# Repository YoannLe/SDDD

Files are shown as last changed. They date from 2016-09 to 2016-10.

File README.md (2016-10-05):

# SDDD

This is a simple direct drive desulfaltor for lead acid battery 12V blocs

You can find schematic, PCB and Gerber files to build a direct drive desulfaltor circuit. This circuit pulses a high current from 30 to 100A at about 2kHz into the battery block to break lead sulfate cristals.

The pulse board drives MOSFET with impulsions from 555 and discharges the capacitor bank into the battery bloc. The capacitor bank is load at 30V DC through a 10W resistor to limit charge current, different values of resistors can be selected to adapt the power of desulfator to the sulfated battery.
Capacitor bank is made with very low ESR electrolytic caps in parallel, the capacity is about 30 mf, in my case:  30 x 1000µf 63V ESR=43mΩ PANASONIC EEUFC1J102U

# SDDD Pulse Board

The main board is the pulse generator board, it drives Mosfets:

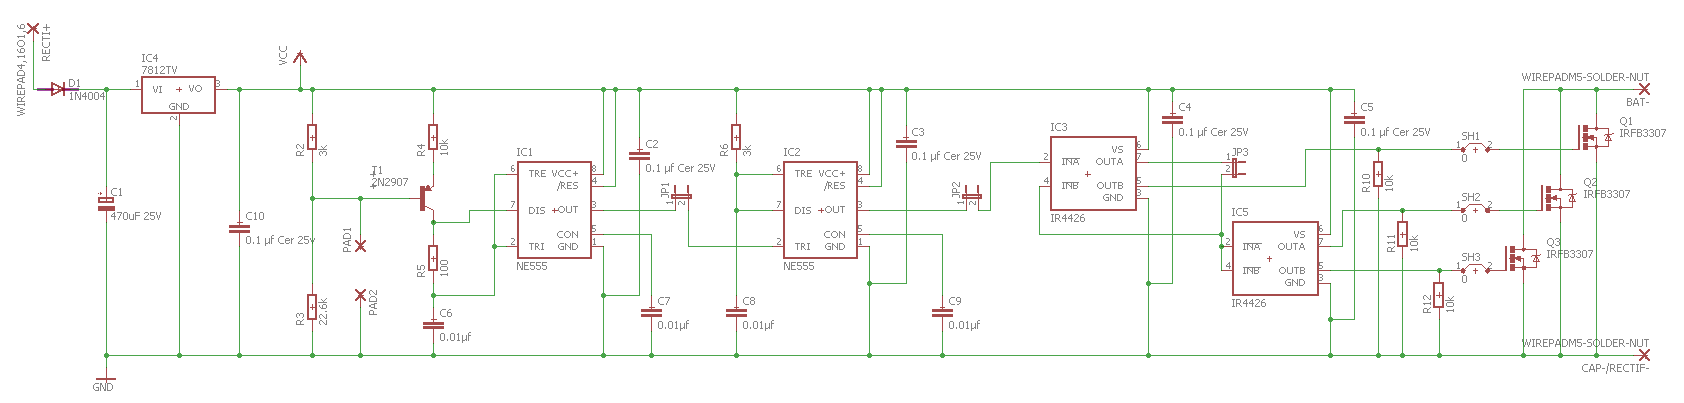
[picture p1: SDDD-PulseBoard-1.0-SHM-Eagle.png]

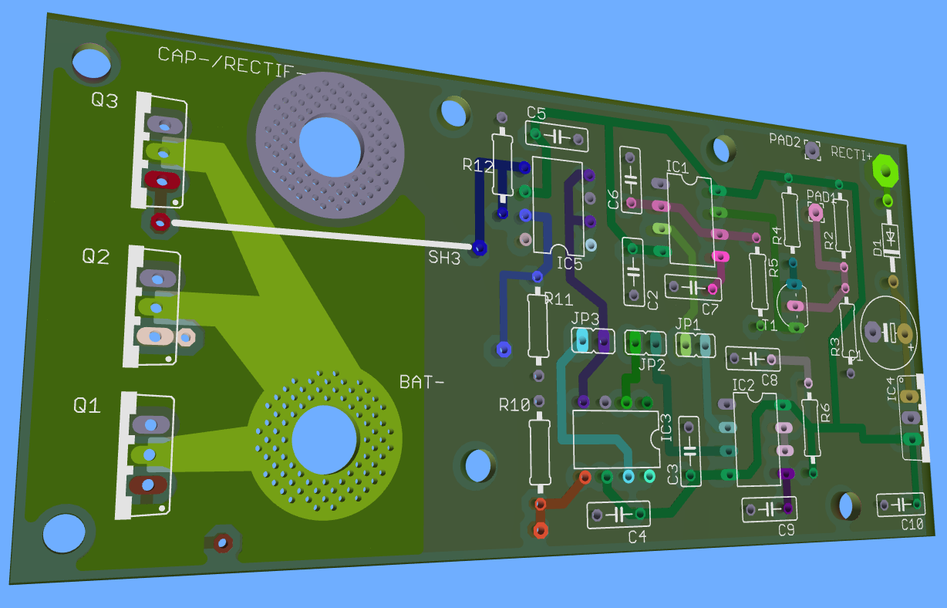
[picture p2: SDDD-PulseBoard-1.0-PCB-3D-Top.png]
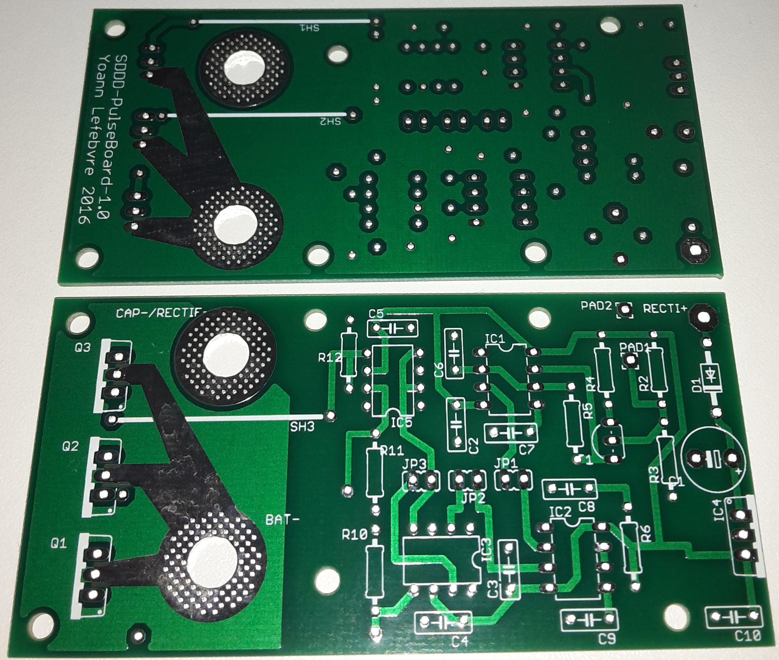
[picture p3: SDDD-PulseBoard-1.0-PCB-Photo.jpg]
 

Frequency and pulses timming can be calculated as described by Tucsonshooter:

>Pulse width = 1.1 * R6 * C8         (capacitance in farads,  .01 mF = .00000001 farads). 
>Example: 1.1 * 3000*.00000001 = .000033 seconds or 33 microseconds.
>
>Frequency = (R2 * Vcc - .65(R2+R3)) / (.333 * Vcc * R4(R2+R3) * C6)
>In this case Vcc = 12V
>And remember capacitance is in farads. Watch the parentheses (X +Y) 
>
>Example: (3000 * 12 - .65( 3000 + 22500))/ (.333 * 12 * 10000(3000 + 22500) * .00000001 =    (36000-16575) / 10.1898     = 1906 Hertz
>
>The frequency formula looks complicated but it is just adding and multiplying in the right order. If you break the formula down and put >it in Excell it will be much easier.
>
>Thermistors 
>  Remember - a 3K NTC thermistor will read 3K at room temperature (25 deg. C.). It will read about 1.5K at 45 deg.C.

A 3k NTC could be used for R2 to reduce frequency from 2kHz at 24° to 250Hz at 45°, this reduce the average power in the MOSFET and protects it from overheat on good batteries with low internal resistances. This slows frequency when the sulfated battery recovers its capacity and low internal resistance.

This board can be cut in fonction blocs when opening jumpers, this is usefull for testing and try others configurations. An optocoupler connected to Vcc and PAD1 can be use to stop pulses from an MCU or arduino. Stop pulsing can be usefull to control battery voltage or in case of battery overheating. 

# Capacitor bank and power supply

# Assembly

# Tests

# Results on 12V 90Ah AGM Battery

First if the battery is old and have been over charged, open the sealed battery to check electrolyte level and refill with demineralized water. The level must be just above the glass mast.

#References

Forum Direct Drive Desulfator Design:

http://leadacidbatterydesulfation.yuku.com/topic/1162/Direct%E2%88%92Drive%E2%88%92Desulfator%E2%88%92Design
http://leadacidbatterydesulfation.yuku.com/topic/1246/Simple-Direct-Drive-Desulfator-PCB-thread
http://www.courtiestown.co.uk/fileuploader/download/download/?d=0&file=custom%2Fupload%2FFile-1368475803.pdf

Evolutions:

http://www.brettcave.net/howto/circuits/Battery_LeadAcidDesulfator-DirectDrive-Type2.pdf
http://www.brettcave.net/howto/circuits/Battery_LeadAcidDesulfator-DirectDrive-Type3.pdf

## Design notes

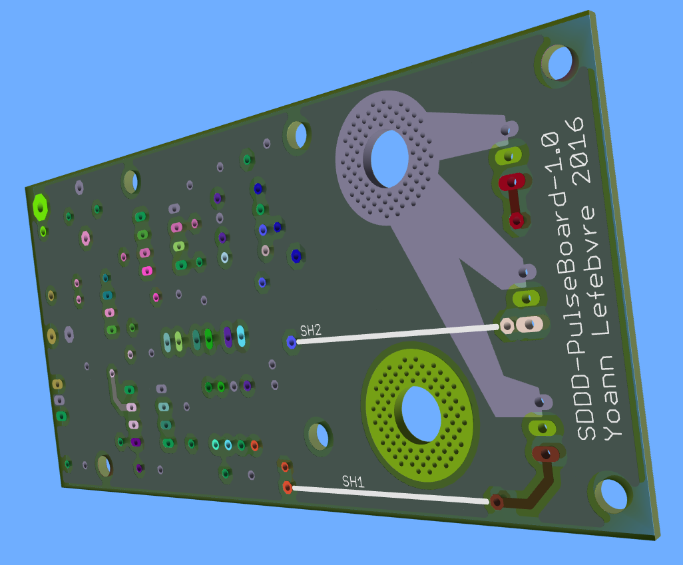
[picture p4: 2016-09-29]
SDDD-PulseBoard-1.0-PCB-3D-Back.png

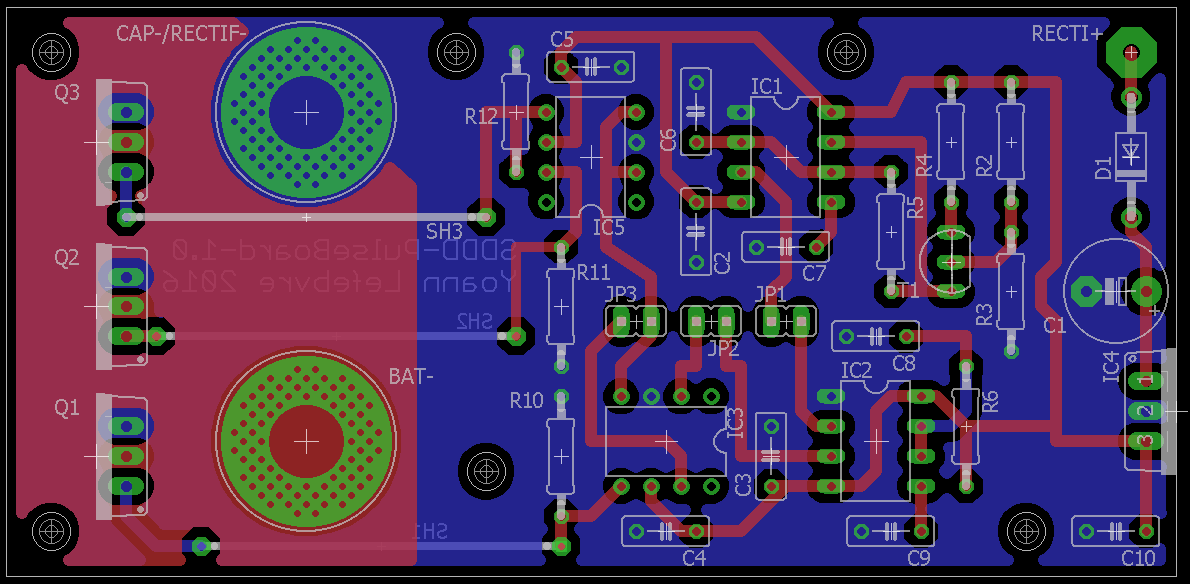
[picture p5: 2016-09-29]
SDDD-PulseBoard-1.0-PCB-Eagle.png

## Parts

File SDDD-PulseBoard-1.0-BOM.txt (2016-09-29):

Partlist exported from D:/ylefebvre/Bureau/SDDD/SDDD-Eagle/SDDD-PulseBoard-1.0.sch at 29/09/2016 18:44

Part         Value                Device                Package       Description                          MF                          MPN       OC_FARNELL OC_NEWARK
BAT-         WIREPADM5-SOLDER-NUT WIREPADM5-SOLDER-NUT  M5-SOLDER-NUT Wire PAD connect wire on PCB                                                                   
C1           470uF 25V            CPOL-EUE5-8.5         E5-8,5        POLARIZED CAPACITOR, European symbol                                                           
C2           0.1 µf Cer 25V       C-EU050-025X075       C050-025X075  CAPACITOR, European symbol                                                                     
C3           0.1 µf Cer 25V       C-EU050-025X075       C050-025X075  CAPACITOR, European symbol                                                                     
C4           0.1 µf Cer 25V       C-EU050-025X075       C050-025X075  CAPACITOR, European symbol                                                                     
C5           0.1 µf Cer 25V       C-EU050-025X075       C050-025X075  CAPACITOR, European symbol                                                                     
C6           0.01µf               C-EU050-025X075       C050-025X075  CAPACITOR, European symbol                                                                     
C7           0.01µf               C-EU050-025X075       C050-025X075  CAPACITOR, European symbol                                                                     
C8           0.01µf               C-EU050-025X075       C050-025X075  CAPACITOR, European symbol                                                                     
C9           0.01µf               C-EU050-025X075       C050-025X075  CAPACITOR, European symbol                                                                     
C10          0.1 µf Cer 25v       C-EU050-025X075       C050-025X075  CAPACITOR, European symbol                                                                     
CAP-/RECTIF- WIREPADM5-SOLDER-NUT WIREPADM5-SOLDER-NUT  M5-SOLDER-NUT Wire PAD connect wire on PCB                                                                   
D1           1N4004               1N4004                DO41-10       DIODE                                                                                          
IC1          NE555                NE555                 DIL-08        General purpose bipolar Timer        Arrow Electronics           NE555N    1467742    89K1486  
IC2          NE555                NE555                 DIL-08        General purpose bipolar Timer        Arrow Electronics           NE555N    1467742    89K1486  
IC3          IR4426               IR4426                DIL08         DUAL LOW SIDE DRIVER                 INTERNATIONAL RECTIFIER(IR) IR4426PBF 1023265    19K8460  
IC4          7812TV               7812TV                TO220V        Positive VOLTAGE REGULATOR                                                                     
IC5          IR4426               IR4426                DIL08         DUAL LOW SIDE DRIVER                 INTERNATIONAL RECTIFIER(IR) IR4426PBF 1023265    19K8460  
JP1                               JP1E                  JP1           JUMPER                                                                                         
JP2                               JP1E                  JP1           JUMPER                                                                                         
JP3                               JP1E                  JP1           JUMPER                                                                                         
PAD1                              2,15/1,0              2,15/1,0      THROUGH-HOLE PAD                                                                               
PAD2                              2,15/1,0              2,15/1,0      THROUGH-HOLE PAD                                                                               
Q1           IRFB3307             IRF540                TO220BV       HEXFET Power MOSFET                                                                            
Q2           IRFB3307             IRF540                TO220BV       HEXFET Power MOSFET                                                                            
Q3           IRFB3307             IRF540                TO220BV       HEXFET Power MOSFET                                                                            
R2           3k                   R-EU_0207/10          0207/10       RESISTOR, European symbol                                                                      
R3           22.6k                R-EU_0207/10          0207/10       RESISTOR, European symbol                                                                      
R4           10k                  R-EU_0207/10          0207/10       RESISTOR, European symbol                                                                      
R5           100                  R-EU_0207/10          0207/10       RESISTOR, European symbol                                                                      
R6           3k                   R-EU_0207/10          0207/10       RESISTOR, European symbol                                                                      
R10          10k                  R-EU_0207/10          0207/10       RESISTOR, European symbol                                                                      
R11          10k                  R-EU_0207/10          0207/10       RESISTOR, European symbol                                                                      
R12          10k                  R-EU_0207/10          0207/10       RESISTOR, European symbol                                                                      
RECTI+       WIREPAD4,16O1,6      WIREPAD4,16O1,6       4,16O1,6      Wire PAD connect wire on PCB                                                                   
SH1          0                    J30MM                 30            Bridge                                                                                         
SH2          0                    J30MM                 30            Bridge                                                                                         
SH3          0                    J30MM                 30            Bridge                                                                                         
T1           2N2907               MPS2907A-PNP-TO92-CBE TO92-CBE      PNP Transistror

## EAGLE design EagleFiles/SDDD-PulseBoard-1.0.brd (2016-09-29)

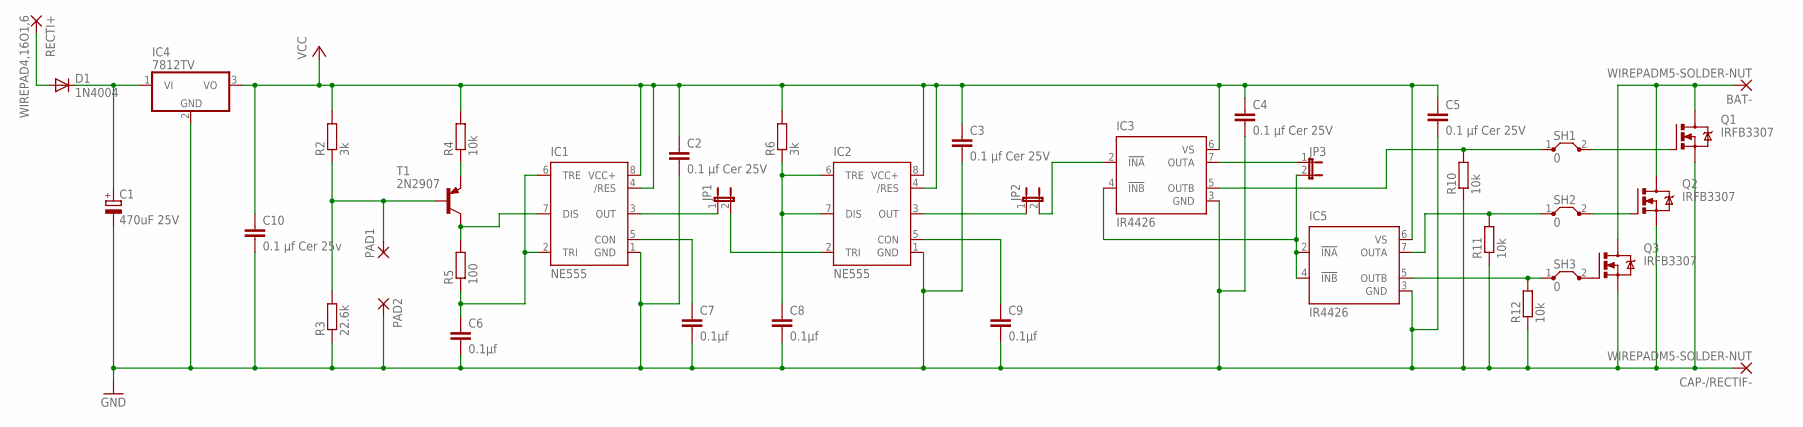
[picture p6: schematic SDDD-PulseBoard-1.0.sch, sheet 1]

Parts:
BAT-: WIREPADM5-SOLDER-NUT; M5-SOLDER-NUT
C1: 470uF 25V; E5-8,5
C2, C3, C4, C5: 0.1 µf Cer 25V; C050-025X075
C6, C7, C8, C9: 0.1µf; C050-025X075
C10: 0.1 µf Cer 25v; C050-025X075
CAP-/RECTIF-: WIREPADM5-SOLDER-NUT; M5-SOLDER-NUT
D1: 1N4004; DO41-10
IC1, IC2: NE555; DIL-08
IC3, IC5: IR4426; DIL08
IC4: 7812TV; TO220V
JP1, JP2, JP3: JP1E; JP1
PAD1, PAD2: 2,15/1,0
Q1, Q2, Q3: IRFB3307; TO220BV
R2, R6: 3k; 0207/10
R3: 22.6k; 0207/10
R4, R10, R11, R12: 10k; 0207/10
R5: 100; 0207/10
RECTI+: WIREPAD4,16O1,6; 4,16O1,6
SH1, SH2, SH3: 0; 30
T1: 2N2907; TO92-CBE

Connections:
GND: C1.-, C2.2, C3.2, C4.2, C5.2, C6.2, C7.2, C8.2, C9.2, C10.2, CAP-/RECTIF-.1, CAP-/RECTIF-.P$1, CAP-/RECTIF-.P$2, CAP-/RECTIF-.P$3, CAP-/RECTIF-.P$4, CAP-/RECTIF-.P$5, CAP-/RECTIF-.P$6, CAP-/RECTIF-.P$7, CAP-/RECTIF-.P$8, CAP-/RECTIF-.P$9, CAP-/RECTIF-.P$10, CAP-/RECTIF-.P$11, CAP-/RECTIF-.P$12, CAP-/RECTIF-.P$13, CAP-/RECTIF-.P$14, CAP-/RECTIF-.P$15, CAP-/RECTIF-.P$16, CAP-/RECTIF-.P$17, CAP-/RECTIF-.P$18, CAP-/RECTIF-.P$19, CAP-/RECTIF-.P$20, CAP-/RECTIF-.P$21, CAP-/RECTIF-.P$22, CAP-/RECTIF-.P$23, CAP-/RECTIF-.P$24, CAP-/RECTIF-.P$25, CAP-/RECTIF-.P$26, CAP-/RECTIF-.P$27, CAP-/RECTIF-.P$28, CAP-/RECTIF-.P$29, CAP-/RECTIF-.P$30, CAP-/RECTIF-.P$31, CAP-/RECTIF-.P$32, CAP-/RECTIF-.P$33, CAP-/RECTIF-.P$34, CAP-/RECTIF-.P$35, CAP-/RECTIF-.P$36, CAP-/RECTIF-.P$37, CAP-/RECTIF-.P$38, CAP-/RECTIF-.P$39, CAP-/RECTIF-.P$40, CAP-/RECTIF-.P$41, CAP-/RECTIF-.P$42, CAP-/RECTIF-.P$43, CAP-/RECTIF-.P$44, CAP-/RECTIF-.P$45, CAP-/RECTIF-.P$46, CAP-/RECTIF-.P$47, CAP-/RECTIF-.P$48, CAP-/RECTIF-.P$49, CAP-/RECTIF-.P$50, CAP-/RECTIF-.P$51, CAP-/RECTIF-.P$52, CAP-/RECTIF-.P$53, CAP-/RECTIF-.P$54, CAP-/RECTIF-.P$55, CAP-/RECTIF-.P$56, CAP-/RECTIF-.P$57, CAP-/RECTIF-.P$58, CAP-/RECTIF-.P$59, CAP-/RECTIF-.P$60, CAP-/RECTIF-.P$61, CAP-/RECTIF-.P$62, CAP-/RECTIF-.P$63, CAP-/RECTIF-.P$64, CAP-/RECTIF-.P$65, CAP-/RECTIF-.P$66, CAP-/RECTIF-.P$67, CAP-/RECTIF-.P$68, CAP-/RECTIF-.P$69, CAP-/RECTIF-.P$70, CAP-/RECTIF-.P$71, CAP-/RECTIF-.P$72, CAP-/RECTIF-.P$73, CAP-/RECTIF-.P$74, CAP-/RECTIF-.P$75, CAP-/RECTIF-.P$76, CAP-/RECTIF-.P$77, CAP-/RECTIF-.P$78, CAP-/RECTIF-.P$79, CAP-/RECTIF-.P$80, IC1.1 (GND), IC2.1 (GND), IC3.3 (GND), IC4.2 (GND), IC5.3 (GND), PAD2.1, Q1.S, Q2.S, Q3.S, R3.1, R10.1, R11.1, R12.1
unnamed: IC3.5 (OUTB), R10.2, SH1.1
unnamed: PAD1.1, R2.1, R3.2, T1.B
unnamed: C6.1, IC1.2 (TRI), IC1.6 (TRE), R5.1
unnamed: Q1.G, SH1.2
unnamed: BAT-.1, BAT-.P$1, BAT-.P$2, BAT-.P$3, BAT-.P$4, BAT-.P$5, BAT-.P$6, BAT-.P$7, BAT-.P$8, BAT-.P$9, BAT-.P$10, BAT-.P$11, BAT-.P$12, BAT-.P$13, BAT-.P$14, BAT-.P$15, BAT-.P$16, BAT-.P$17, BAT-.P$18, BAT-.P$19, BAT-.P$20, BAT-.P$21, BAT-.P$22, BAT-.P$23, BAT-.P$24, BAT-.P$25, BAT-.P$26, BAT-.P$27, BAT-.P$28, BAT-.P$29, BAT-.P$30, BAT-.P$31, BAT-.P$32, BAT-.P$33, BAT-.P$34, BAT-.P$35, BAT-.P$36, BAT-.P$37, BAT-.P$38, BAT-.P$39, BAT-.P$40, BAT-.P$41, BAT-.P$42, BAT-.P$43, BAT-.P$44, BAT-.P$45, BAT-.P$46, BAT-.P$47, BAT-.P$48, BAT-.P$49, BAT-.P$50, BAT-.P$51, BAT-.P$52, BAT-.P$53, BAT-.P$54, BAT-.P$55, BAT-.P$56, BAT-.P$57, BAT-.P$58, BAT-.P$59, BAT-.P$60, BAT-.P$61, BAT-.P$62, BAT-.P$63, BAT-.P$64, BAT-.P$65, BAT-.P$66, BAT-.P$67, BAT-.P$68, BAT-.P$69, BAT-.P$70, BAT-.P$71, BAT-.P$72, BAT-.P$73, BAT-.P$74, BAT-.P$75, BAT-.P$76, BAT-.P$77, BAT-.P$78, BAT-.P$79, BAT-.P$80, Q1.D, Q2.D, Q3.D
unnamed: IC5.7 (OUTA), R11.2, SH2.1
unnamed: Q2.G, SH2.2
unnamed: IC5.5 (OUTB), R12.2, SH3.1
unnamed: R4.1, T1.E
unnamed: IC1.7 (DIS), R5.2, T1.C
unnamed: Q3.G, SH3.2
unnamed: C7.1, IC1.5 (CON)
unnamed: C8.1, IC2.6 (TRE), IC2.7 (DIS), R6.1
unnamed: IC1.3 (OUT), JP1.1
unnamed: IC2.2 (TRI), JP1.2
unnamed: IC2.3 (OUT), JP2.1
unnamed: IC3.2 (!INA), JP2.2
unnamed: IC3.7 (OUTA), JP3.1
unnamed: IC3.4 (!INB), IC5.2 (!INA), IC5.4 (!INB), JP3.2
unnamed: C1.+, D1.C, IC4.1 (VI)
unnamed: C9.1, IC2.5 (CON)
unnamed: D1.A, RECTI+.1
VCC: C2.1, C3.1, C4.1, C5.1, C10.1, IC1.4 (/RES), IC1.8 (VCC+), IC2.4 (/RES), IC2.8 (VCC+), IC3.6 (VS), IC4.3 (VO), IC5.6 (VS), R2.2, R4.2, R6.2

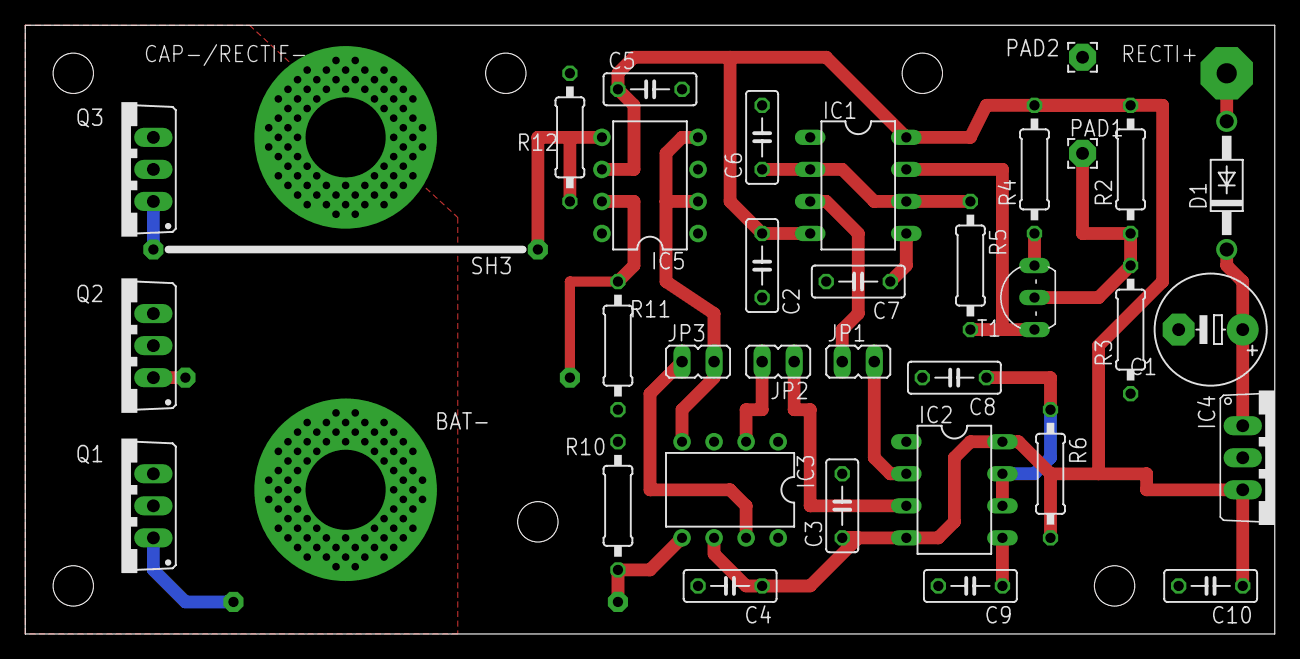
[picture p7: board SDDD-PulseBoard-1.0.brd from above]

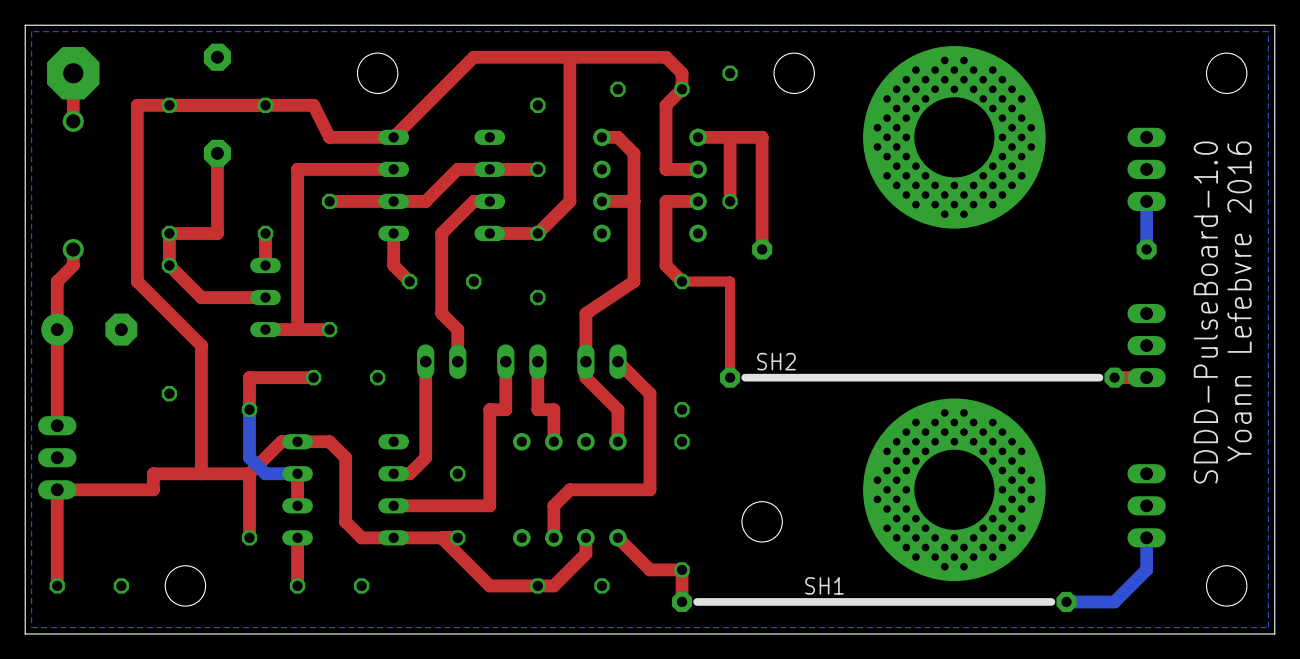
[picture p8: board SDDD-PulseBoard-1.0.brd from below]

Board: 2 copper layers, 99.1 x 48.3 mm, 39 parts (2 on the bottom side), 24 nets.
